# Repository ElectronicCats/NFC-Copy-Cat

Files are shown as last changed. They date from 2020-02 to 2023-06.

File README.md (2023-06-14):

# NFC Copy Cat

NFC Copy Cat, manufactured by Electronic Cats, is a small device that combines two powerful cybersecurity tools, NFCopy and MagSpoof. NFCopy works by reading or emulating an NFC card; depending on the necessities of the researcher. On the other hand, MagSpoof can wirelessly emulate/spoof any magnetic stripe card. So using NFC Copy Cat, the user will have a device capable of storing magnetic stripe data or NFC payment data to be replayed later — known in the cybersecurity world as a replay attack. 

To show the capabilities of NFC Copy Cat, the emulation example will use a Visa MSD protocol. So be aware that this type of transaction will not be accepted in some payment systems.

NFC Copy Cat combines a simple user interface that can be programmed using Arduino IDE. Adding a micro USB connection, 3.7V LiPo battery connector, antenna, two programmable buttons, LEDs and a reset button. The most important part, NFC Copy Cat is an open hardware project. So anyone could modify or redesign it on their own.

Devices like NFC Copy Cat are essential for researchers, students, teachers or anyone interested in payment systems. It will help to understand how the payment system works, the communications or the APDU protocol. 

Some of the code examples that will be available introduce different concepts. For example, how to detect a card reader, how to detect an NFC card, how to use MagSpoof using a button as a trigger to spoof, how to use NFC with a button to emulate, how to read a Visa card, how to emulate a Visa MSD card, how to generate challenges to extract card information or how to combine both tools: NFCopy and MagSpoof.

## Features:
- Microcontroller SAMD21 ARM 32-bit Cortex M0
- Memory Flash for support Circuit Python
- Battery Charger 3.7v
- Compatible con Adafruit PN532 breakout
- Compatible con NFC Module V3

### Included Complete Version:
- NFC Copy Cat
- Coil for Magspoof
- NFC Module V3 +Tag 
### Included Single Version:
- NFC Copy Cat
- Coil for Magspoof

<a href="https://electroniccats.com/store/nfc-copy-cat/">
  
</a>

## Wiki and Getting Started
[Getting Started in our Wiki](https://github.com/ElectronicCats/NFC-Copy-Cat/wiki)



## Disclaimer
NFC Copy Cat is a wireless penetration testing tool intended solely for use in authorized security audits, where such usage is permitted by applicable laws and regulations. Before utilizing this tool, it is crucial to ensure compliance with all relevant legal requirements and obtain appropriate permissions from the relevant authorities.

It is essential to note that the board does not provide any means or authorization to utilize credit cards or engage in any financial transactions that are not legally authorized. Electronic Cats holds no responsibility for any unauthorized use of the tool or any resulting damages.

## License
OpenSourceLicense

Electronic Cats invests time and resources providing this open source design, please support Electronic Cats and open-source hardware by purchasing products from Electronic Cats!

Designed by Electronic Cats.

Firmware released under an GNU AGPL v3.0 license. See the LICENSE file for more information.

Hardware released under an CERN Open Hardware Licence v1.2. See the LICENSE_HARDWARE file for more information.

Electronic Cats is a registered trademark, please do not use if you sell these PCBs.

8 July 2019

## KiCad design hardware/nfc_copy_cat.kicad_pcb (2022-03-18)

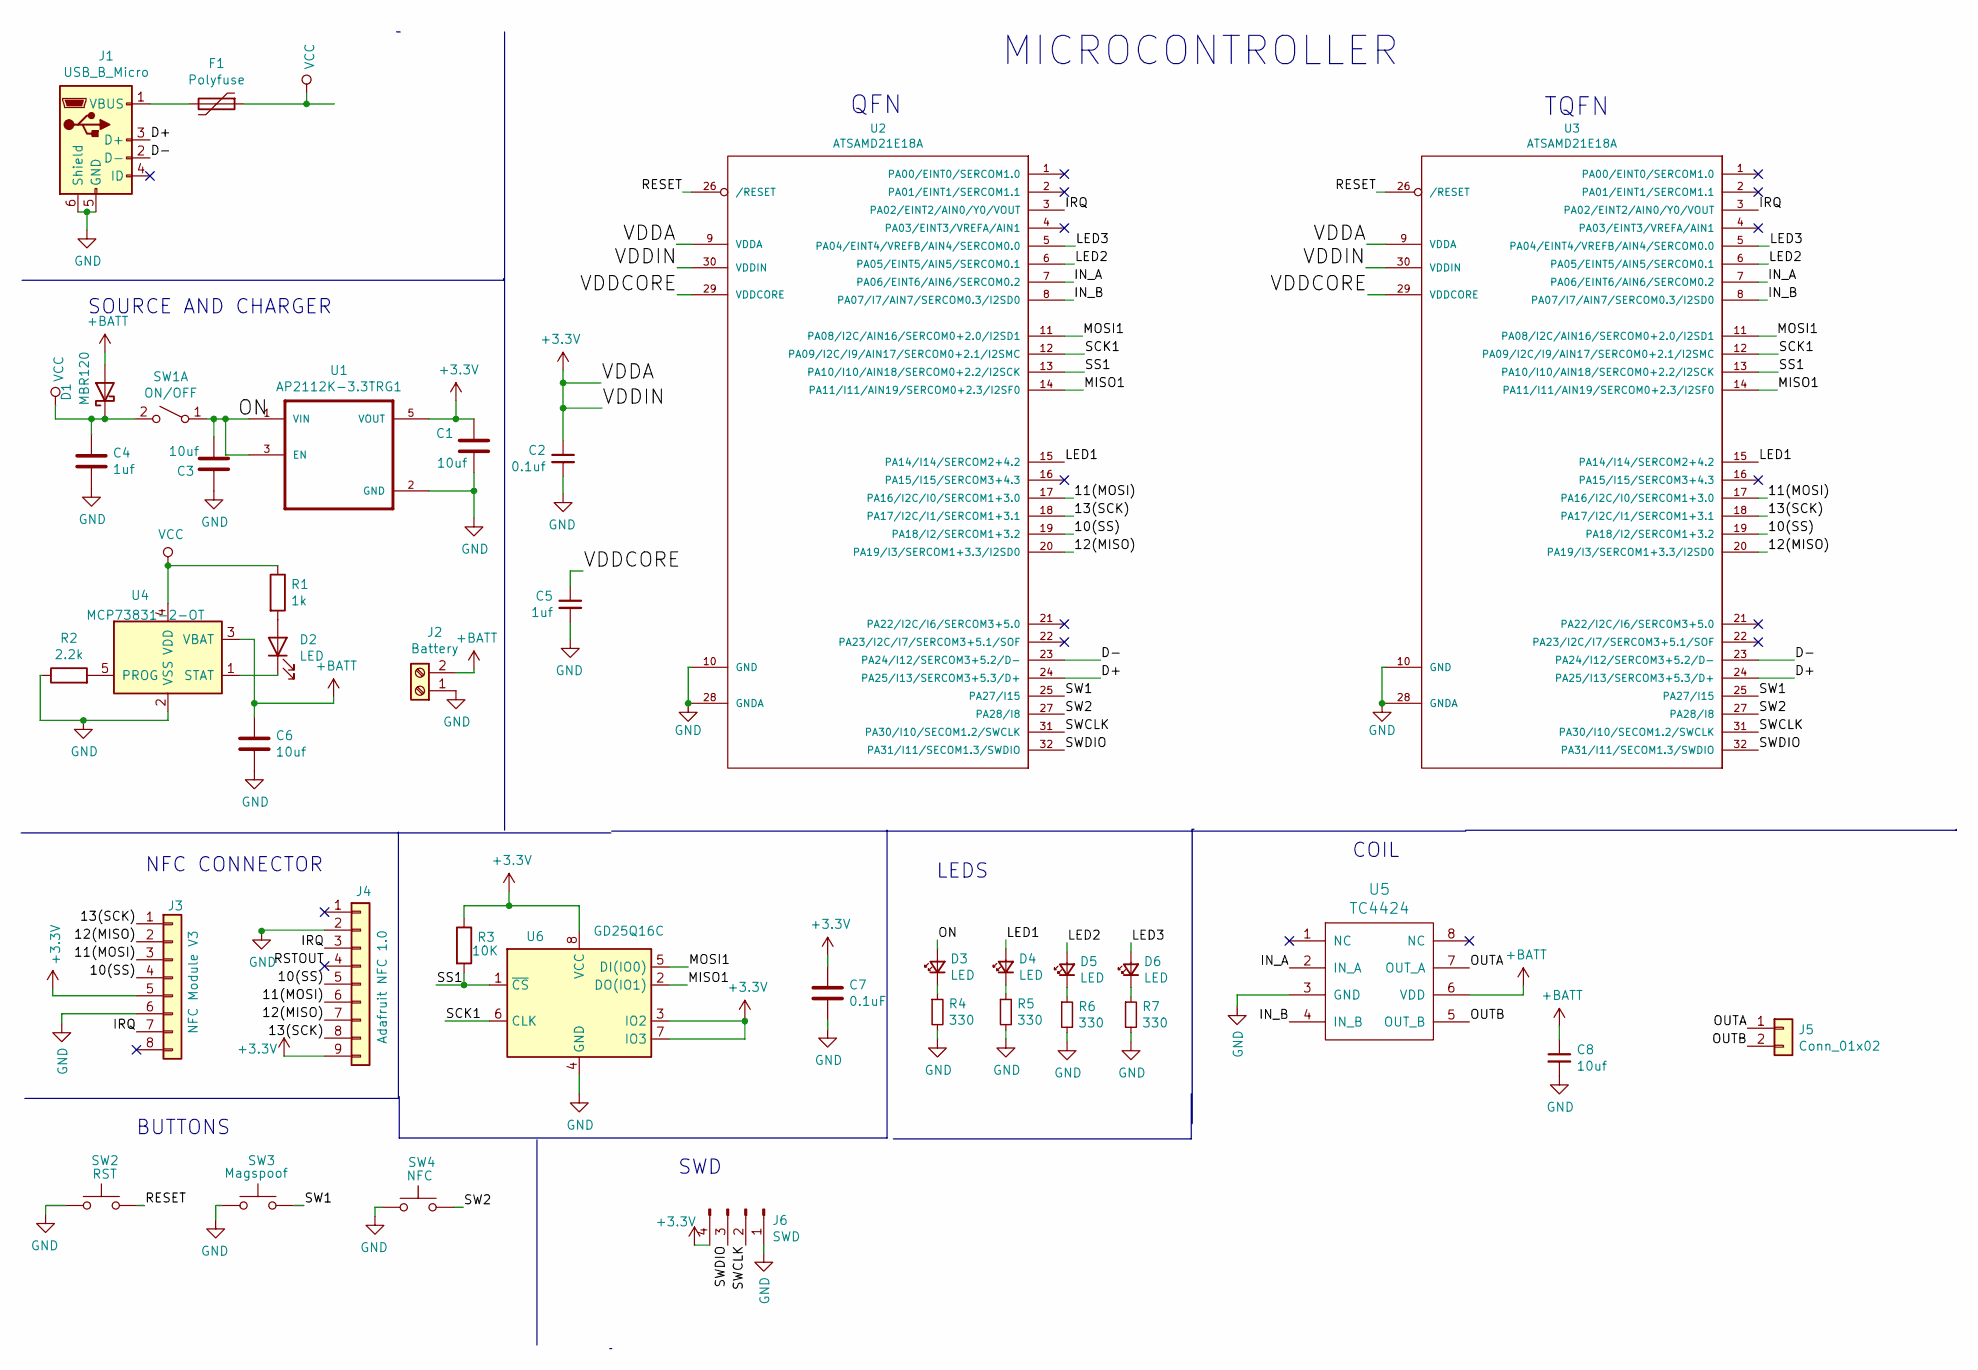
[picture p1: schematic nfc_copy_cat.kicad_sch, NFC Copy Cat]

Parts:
C1, C3, C6, C8: 10uf; C_0805_2012Metric_Pad1.15x1.40mm_HandSolder
C2: 0.1uf; C_0805_2012Metric_Pad1.15x1.40mm_HandSolder
C4, C5: 1uf; C_0805_2012Metric_Pad1.15x1.40mm_HandSolder
C7: 0.1uF; C_0805_2012Metric_Pad1.15x1.40mm_HandSolder
D1: MBR120; D_SOD-123
D2, D3, D4, D5, D6: LED; LED_0805_2012Metric_Pad1.15x1.40mm_HandSolder
F1: Polyfuse; Fuse_0805_2012Metric_Pad1.15x1.40mm_HandSolder
J1: USB_B_Micro; U254051N4BH806
J2: Battery; PinHeader_1x02_P2.54mm_Vertical
J3: NFC Module V3; PinHeader_1x08_P2.54mm_Vertical
J4: Adafruit NFC 1.0; PinHeader_1x09_P2.54mm_Vertical
J5: Conn_01x02; PinHeader_1x02_P2.54mm_Vertical
J6: SWD; PinHeader_1x04_P2.54mm_Vertical
R1: 1k; R_0805_2012Metric
R2: 2.2k; R_0805_2012Metric_Pad1.15x1.40mm_HandSolder
R3: 10K; R_0805_2012Metric_Pad1.15x1.40mm_HandSolder
R4: 330; R_0805_2012Metric
R5, R6, R7: 330; R_0805_2012Metric_Pad1.15x1.40mm_HandSolder
SW1: ON/OFF; Micro_interruptor_SPDT
SW2: RST; SW_SPST_TL3342
SW3: Magspoof; SW_SPST_TL3342
SW4: NFC; SW_SPST_TL3342
U1: AP2112K-3.3TRG1; SOT-23-5_HandSoldering
U2: ATSAMD21E18A; QFN-32-1EP_5x5mm_P0.5mm_EP3.6x3.6mm
U3: ATSAMD21E18A; TQFP-32_7x7mm_P0.8mm
U4: MCP73831-2-OT; SOT-23-5
U5: TC4424; SOIC-8_3.9x4.9mm_P1.27mm
U6: GD25Q16C; SOIC-8_5.23x5.23mm_P1.27mm

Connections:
+3V3: C1.1, C2.1, C7.1, J3.5, J4.9, J6.4, R3.1, U1.5 (VOUT), U2.9 (VDDA), U2.30 (VDDIN), U3.9 (VDDA), U3.30 (VDDIN), U6.3 (IO2), U6.7 (IO3), U6.8 (VCC)
+BATT: C6.1, C8.1, D1.2 (A), J2.2, U4.3 (VBAT), U5.6 (VDD)
/10(SS): J3.4, J4.5, U2.19 (PA18/I2/SERCOM1+3.2), U3.19 (PA18/I2/SERCOM1+3.2)
/11(MOSI): J3.3, J4.6, U2.17 (PA16/I2C/I0/SERCOM1+3.0), U3.17 (PA16/I2C/I0/SERCOM1+3.0)
/12(MISO): J3.2, J4.7, U2.20 (PA19/I3/SERCOM1+3.3/I2SD0), U3.20 (PA19/I3/SERCOM1+3.3/I2SD0)
/13(SCK): J3.1, J4.8, U2.18 (PA17/I2C/I1/SERCOM1+3.1), U3.18 (PA17/I2C/I1/SERCOM1+3.1)
/D+: J1.3 (D+), U2.24 (PA25/I13/SERCOM3+5.3/D+), U3.24 (PA25/I13/SERCOM3+5.3/D+)
/D-: J1.2 (D-), U2.23 (PA24/I12/SERCOM3+5.2/D-), U3.23 (PA24/I12/SERCOM3+5.2/D-)
/IN_A: U2.7 (PA06/EINT6/AIN6/SERCOM0.2), U3.7 (PA06/EINT6/AIN6/SERCOM0.2), U5.2 (IN_A)
/IN_B: U2.8 (PA07/I7/AIN7/SERCOM0.3/I2SD0), U3.8 (PA07/I7/AIN7/SERCOM0.3/I2SD0), U5.4 (IN_B)
/IRQ: J3.7, J4.3, U2.3 (PA02/EINT2/AIN0/Y0/VOUT), U3.3 (PA02/EINT2/AIN0/Y0/VOUT)
/LED1: D4.2 (A), U2.15 (PA14/I14/SERCOM2+4.2), U3.15 (PA14/I14/SERCOM2+4.2)
/LED2: D5.2 (A), U2.6 (PA05/EINT5/AIN5/SERCOM0.1), U3.6 (PA05/EINT5/AIN5/SERCOM0.1)
/LED3: D6.2 (A), U2.5 (PA04/EINT4/VREFB/AIN4/SERCOM0.0), U3.5 (PA04/EINT4/VREFB/AIN4/SERCOM0.0)
/MISO1: U2.14 (PA11/I11/AIN19/SERCOM0+2.3/I2SF0), U3.14 (PA11/I11/AIN19/SERCOM0+2.3/I2SF0), U6.2 (DO(IO1))
/MOSI1: U2.11 (PA08/I2C/AIN16/SERCOM0+2.0/I2SD1), U3.11 (PA08/I2C/AIN16/SERCOM0+2.0/I2SD1), U6.5 (DI(IO0))
/OUTA: J5.1, U5.7 (OUT_A)
/OUTB: J5.2, U5.5 (OUT_B)
/RESET: SW2.2, U2.26 (/RESET), U3.26 (/RESET)
/RSTOUT: J4.4
/SCK1: U2.12 (PA09/I2C/I9/AIN17/SERCOM0+2.1/I2SMC), U3.12 (PA09/I2C/I9/AIN17/SERCOM0+2.1/I2SMC), U6.6 (CLK)
/SS1: R3.2, U2.13 (PA10/I10/AIN18/SERCOM0+2.2/I2SCK), U3.13 (PA10/I10/AIN18/SERCOM0+2.2/I2SCK), U6.1 (~CS)
/SW1: SW3.2, U2.25 (PA27/I15), U3.25 (PA27/I15)
/SW2: SW4.2, U2.27 (PA28/I8), U3.27 (PA28/I8)
/SWCLK: J6.2, U2.31 (PA30/I10/SECOM1.2/SWCLK), U3.31 (PA30/I10/SECOM1.2/SWCLK)
/SWDIO: J6.3, U2.32 (PA31/I11/SECOM1.3/SWDIO), U3.32 (PA31/I11/SECOM1.3/SWDIO)
/VDDCORE: C5.1, U2.29 (VDDCORE), U3.29 (VDDCORE)
GND: C1.2, C2.2, C3.2, C4.2, C5.2, C6.2, C7.2, C8.2, J1.5 (GND), J1.6 (Shield), J2.1, J3.6, J4.2, J6.1, R2.1, R4.2, R5.2, R6.2, R7.2, SW2.1, SW3.1, SW4.1, U1.2 (GND), U2.10 (GND), U2.28 (GNDA), U3.10 (GND), U3.28 (GNDA), U4.2 (VSS), U5.3 (GND), U6.4 (GND)
unnamed: D2.1 (K), U4.1 (STAT)
unnamed: D2.2 (A), R1.2
unnamed: D3.1 (K), R4.1
unnamed: D4.1 (K), R5.1
unnamed: D5.1 (K), R6.1
unnamed: D6.1 (K), R7.1
unnamed: F1.2, J1.1 (VBUS)
unnamed: R2.2, U4.5 (PROG)

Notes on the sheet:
QFN
NFC CONNECTOR
LEDS
SWD
TQFN
SOURCE AND CHARGER
COIL
BUTTONS
MICROCONTROLLER

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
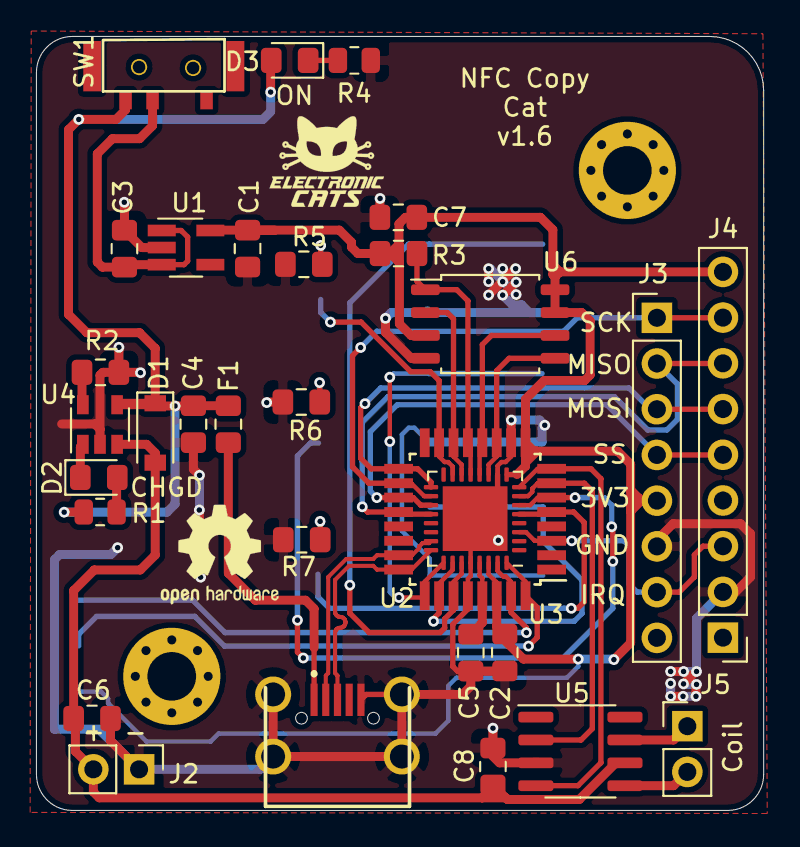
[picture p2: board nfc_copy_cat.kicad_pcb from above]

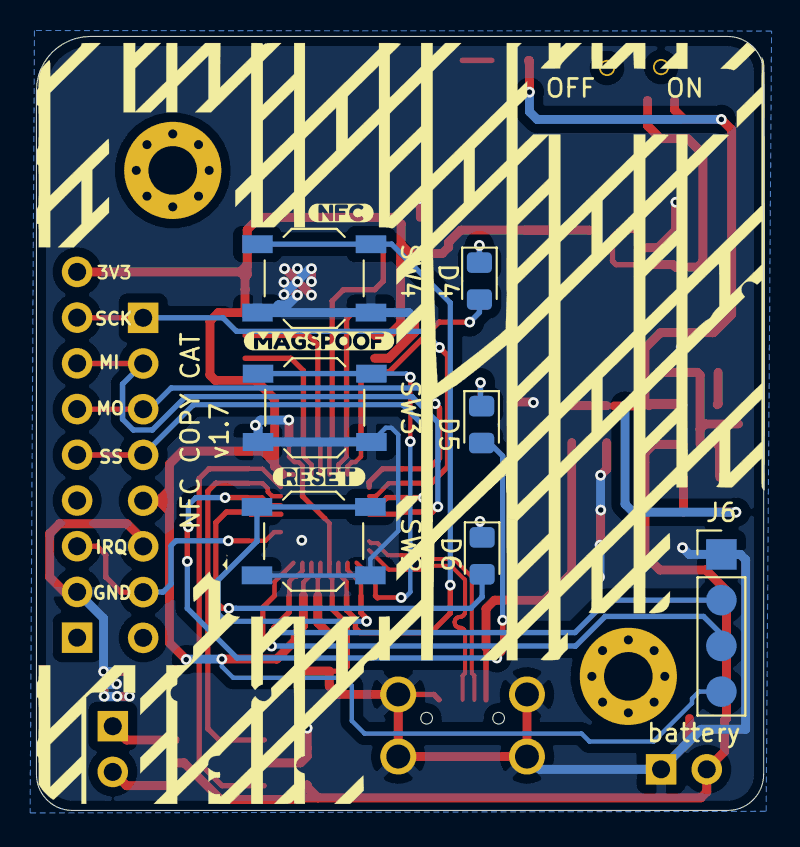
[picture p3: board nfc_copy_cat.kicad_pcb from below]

Board: 2 copper layers, 40.4 x 43.0 mm, 43 parts (10 on the bottom side), 37 nets.

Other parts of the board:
 : MountingHole_2.7mm_M2.5_Pad_Via
 #2: MountingHole_2.7mm_M2.5_Pad_Via
kibuzzard-6234C9E0: G***; kibuzzard-6234C9E0
kibuzzard-6234C9F1: G***; kibuzzard-6234C9F1
kibuzzard-6234C9FD: G***; kibuzzard-6234C9FD

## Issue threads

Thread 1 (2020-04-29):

bootloader

K1two2, 2020-04-29:
NFC Copy Cat is an interesting project. I made several PCBs. How can I burn the bootloader?

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

sabas1080, 2020-04-29:
@K1two2 Hi, wow interesting, for burn bootloader you can use a SWD programmer as Jlink or Baclkmagic in J3

Binary available in https://github.com/ElectronicCats/Arduino_Boards_Index/tree/gh-pages/electroniccats/samd/bootloaders/nfc_copy_cat

K1two2, 2020-04-29:
Thank you, sir ~
I have been trying to search for information about the uf2 bootloader, and it turns out that there are ready-made BIN firmware downloads in the Arduino Boards Index.
hahaha~

K1two2, 2020-04-29:
> @K1two2 Hi, wow interesting, for burn bootloader you can use a SWD programmer as Jlink or Baclkmagic in J3
>
> Binary available in https://github.com/ElectronicCats/Arduino_Boards_Index/tree/gh-pages/electroniccats/samd/bootloaders/nfc_copy_cat

Thank you, sir ~
I have been trying to search for information about the uf2 bootloader, and it turns out that there are ready-made BIN firmware downloads in the Arduino Boards Index.
hahaha~

sabas1080, 2020-04-30:
Oh when you compile UF2 generate various binaries https://github.com/ElectronicCats/uf2-samd21/tree/master/boards/nfc_copy_cat

joelsernamoreno, 2021-06-06:
Hi!

The bootloader (binary) link does not exist. Where can I find it?

Thanks!

sabas1080, 2021-06-07:
@joelsernamoreno binary file in our arduiino core https://github.com/ElectronicCats/ArduinoCore-samd/tree/master/bootloaders/nfc_copy_cat

Closed 2020-04-29.

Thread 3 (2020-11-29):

Hardware setup imformation

Pdubs19, 2020-11-29:
Hey can you send some info on how to hook up and program the board with arduino mega 2560. Also any pictures and basic hardware/hookup support would be appreciated.

sabas1080, 2020-11-29:
Can you explain a little more what you want to do? NFC copy cat uses a SAMD21

Pdubs19, 2020-11-29:
Just want to be able to run the nfc read and be able to spoof magstripes.
So really the read replay spoof code. I'm new to programming circuit
boards. I have an arduino uno and mega. I'm just looking for a little more
info on how the board works. Do I just need to program the pn532 board and
connect it to the nfc copycat board. I got the nfc copycat into bootloader
mode but am not really sure how to program the nfc and magspoof buttons

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

Pdubs19, 2020-11-29:
The samd21 mi

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

Pdubs19, 2020-11-29:
I have the samd21 micro controller nfc copy cat 1.4v board with the electro
house nfc v3 board.

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

sabas1080, 2020-11-30:
@Pdubs19 Have you already consulted our wiki?

https://github.com/ElectronicCats/NFC-Copy-Cat/wiki

Pdubs19, 2020-11-30:
Yes. All I'm really wondering is if I need to program either the nfc
copycat samd21 board or the pn532 nxp board separately or if I only have to
program one of them and then connect the boards together. Ik this is a
newbie question but I really want to make this device work. Also does the
samd21 board coil connect to the nxp pn532 coil somehow for the read replay
spoof programming

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

Pdubs19, 2020-11-30:
Don't want to waste anyone's time but anymore pictures and basic info on
how to start and which boards have to be programmed and what order etc.
would be greatly apprecisted.

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

Pdubs19, 2020-12-05:
For Magpoof coil

#define L1 (14) //LED1

#define L2 (5) //LED2

#define L3 (4) //LED3

For Buttons

#define MPIN (28) //MagsSpoof Button

#define NPIN (27) //NFC Button

Does this mean I need to connect the LED 1 to 14 on the arduino?  If so what it's the connection for LED 1 on the nfc samd21 nfc board?

FelipeIslas, 2020-12-10:
Hi @Pdubs19
We are using our NFC Copy-Cat, which as you say has a SAMD21, this board has 3 onboard programmable LEDs and they are on pin 14, 4 and 5, so in the example these numbers are used for those LEDs.
Our Wiki was Updated, now it is a little clearer!!! I recommend you see it to clarify some of your doubts

Pdubs19, 2020-12-11:
Yo thanks for the new wiki feels like Christmas has come early. I'm totally new to programming but couldn't resist buying the nfc copy cat once I read about it.

Closed 2020-12-11.

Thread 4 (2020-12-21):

Is there a program or tutorial to decode the nfc tag data or msd data?

Pdubs19, 2020-12-21:
Is there any tutorials of sites with more info on decrypting nfc data and converting it to magstripe data. My main question is why is Magstripe data so important? How did Samy Kamkar figure out what parts of track 2 discretionary data needed to be changed in order to downgrade the service code from 201 to 101. Was his downgrade method simply using his algorithim to use a previous cards CVC3 or CVV2 on the magstripe and apply it to the new card?

Pdubs19, 2020-12-29:
Any suggestions for the best programs to use for going through the nfc data while using arduino? Rn I've been using arduino's serial monitor or putty connected to the serial port.

Pdubs19, 2020-12-29:
Any ideas on the best software to use for decrypting the nfc data on windows 10

salmg, 2020-12-29:
Hello @Pdubs19

Answering your questions:
1. "is why is Magstripe data so important?" - Because it what the payment systems implements to charge amount to an account. The mag-stripe contains all the necessary data to do that, such as, PAN, expiration date, service code, discretionary data...

2. "How did Samy Kamkar figure out what parts of track 2 discretionary data needed to be changed in order to downgrade the service code from 201 to 101." - It is a legacy compatibility in the payment systems to be able to do different payments without denying most of the transactions & because Samy is so smart.

3. "Was his downgrade method simply using his algorithim to use a previous cards CVC3 or CVV2 on the magstripe and apply it to the new card?" - This replay attack only works in the Visa cards CVV mag-stripe data, as I mentioned before it works because compatibility.

4. "Does this device not save the info in order to spoof nfc and magspoof once the power is disconnected." - No, the device will not save the data that read afterwards. It will only save the track you assigned in the code.

To decode EMV, you can read the books in NFC Forum: https://www.emvco.com/emv-technologies/contact/

An online service that helps to decode EMV data automatically: https://emvlab.org/tlvutils/

Closed 2020-12-31.

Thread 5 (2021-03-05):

Help with PDOL challenge

merdeux50, 2021-03-05:
Hello,

I’ve recently gotten a nfc copy cat and am struggling to understand how to run the read_replay_spoof .ino

could someone please clarify what “ Make a right format challenge using the card PDOL to extract more data(track 2)” means? And how I should go editing the ino?

ive successfully got my cards pdol with the acr122 and cardpeek what next?

salmg, 2021-03-07:
If you got the pdol from the acr122 means that you got the track 2 as well.

Just add the track 2 to the token variable. There is an example in the code such as

 char token[19] = {0x44,0x12,0x34,0x15,0x01,0x12,0x03,0x12,0xd2,0x41,0x12,0x01,0x10,0x12,0x09,0x99,0x99,0x99,0x1f};

and then emulate it.

merdeux50, 2021-03-07:
Thank you for your reply, yes I can use it. But what’s the point in having bought the nfc copy cat with the ability to extract it through the pn 352 if I have to use another device?

How can I successfully use the copy cat?

salmg, 2021-03-07:
The PDOL function was designed to challenge the card, to be able to extract track 2, NFC Copy Cat has to send the correct challenge at least in format to the card. That is what PDOL does. Basically it generates the "GET PROCESSING OPTIONS" command in format, so the card can answer with the track 2

Really you do not have to edit the code to work; this code is ready to use, if you press a button and it will spoof data, if you press the second one, it will try yo read the card automatically.

If you want to learn about what is pdol: https://www.emvco.com/wp-content/uploads/2017/05/EMV_v4.3_Book_3_Application_Specification_20120607062110791.pdf

If you want to learn more about the tool: https://salmg.net/2020/04/13/nfc-copy-cat-magstripe-nfc/ or

merdeux50, 2021-03-08:
Thank you!

I will read all I can to understand the communication with the card.
It seems after trying the CheckPDOL I get (This card is not active btw...)

9.934 -> Command: 0x00 0xA4 0x04 0x00 0x0E 0x32 0x50 0x41 0x59 0x2E 0x53 0x59 0x53 0x2E 0x44 0x44 0x46 0x30 0x31 0x00
09:17:50.006 -> Card answer: 0x6F 0x23 0x84 0x0E 0x32 0x50 0x41 0x59 0x2E 0x53 0x59 0x53 0x2E 0x44 0x44 0x46 0x30 0x31 0xA5 0x11 0xBF 0x0C 0x0E 0x61 0x0C 0x4F 0x07 0xA0 0x00 0x00 0x00 0x03
09:17:50.006 -> -----
09:17:50.331 -> Command: 0x00 0xA4 0x04 0x00 0x07 0xA0 0x00 0x00 0x00 0x03 0x10 0x10 0x00
09:17:50.443 -> Card answer: 0x6F 0x5E 0x84 0x07 0xA0 0x00 0x00 0x00 0x03 0x10 0x10 0xA5 0x53 0x50 0x0B 0x56 0x69 0x73 0x61 0x20 0x43 0x72 0x65 0x64 0x69 0x74 0x87 0x01 0x01 0x9F 0x38 0x18
09:17:50.443 -> -----
09:17:50.443 -> -->PDOL found: 0x18 0x00 0x00 0x00 0x00 0x00 0x00 0x00 0x00 0x00 0x00 0x00 0x00 0x00 0x00 0x00 0x00 0x00 0x00 0x00 0x00 0x00 0x00 0x00 0x00
09:17:50.443 -> -----
09:17:50.757 -> Command: 0x80 0xA8 0x00 0x00 0x23 0x83 0x21 0x00
09:17:50.793 -> Card answer: 0x6F 0x00
09:17:50.793 -> -----
09:17:51.084 -> Command: 0x00 0xB2 0x01 0x0C 0x00
09:17:51.117 -> Card answer: 0x6A 0x83

Comparing the card answer with cardpeek, 3 lines of data are missing in the response to the visa command. That might be why I can't seem to get it to work?

merdeux50, 2021-03-12:
Any insight regarding the pdol check?

merdeux50, 2021-03-18:
After reading most of the documents I found. I’m realizing that the script is fine.
For some reason the cards responses to the APDU and visa is too short for it to get the normal pdol.

There is a communication error somewhere.

The PN532 board is unreliable, it recognizes the board 1 out of 30 times.

Honestly guy, this is supposed to be for students and people that want to learn?
I’ve had an extremely uninterested and lazy response from all of you guys here. Giving me lazy responses.

Just take the money and run type of mentality.

I’m disappointed

wero1414, 2021-03-23:
Hi @merdeux50 im really sorry about the timming on answering your issue, i must say our technical team is quite small and we're now focused on a new product, The Hunter Cat NFC we have noticed on the past the problem with the PN532 board sometimes it works in a bad way, talking in other topic, the maspoof should work as thats something that we always test on our product line

merdeux50, 2021-03-24:
I noticed a crucial thing missing from your wiki which solved most of my issues.

I was using the Adafruit PN532 library, I changed it to salm pn532 library and it works better now.

merdeux50, 2021-03-25:
That’s unbelievable!

You should have told me that you guys were coming out with a new product - nfc hunter cat. Instead I bought the nfc copy cat that doesn’t work because of the crappy PN532 board. Come on guys, why?
You knew I had monetary issues since is asked for a coupon, which was denied.

Closed 2021-03-24.

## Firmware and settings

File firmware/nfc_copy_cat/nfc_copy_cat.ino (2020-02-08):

/************************************************************
  NFC Copy Cat
  by Salvador Mendoza (salmg.net)
  for Electronic Cats
   
  This example demonstrates how to use NFC Copy Cat by Electronic Cats
  https://github.com/ElectronicCats/magspoof
  
  Development environment specifics:
  IDE: Arduino 1.8.9
  Hardware Platform:
  NFC Copy Cat
  - SAMD21E
  
  This code is beerware; if you see me (or any other Electronic Cats
  member) at the local, and you've found our code helpful,
  please buy us a round!
  Distributed as-is; no warranty is given.
*/
#include <Wire.h>
#include <SPI.h>
#include <Adafruit_PN532.h>

#define PN532_SCK  (17)
#define PN532_MOSI (16)
#define PN532_SS   (18)
#define PN532_MISO (19)

#define PN532_IRQ   (2)
#define PN532_RESET (3)

Adafruit_PN532 nfc(PN532_SCK, PN532_MISO, PN532_MOSI, PN532_SS);

#if defined(ARDUINO_ARCH_SAMD)
   #define Serial SerialUSB
#endif
int lectura;
void setup() {
  pinMode(8,OUTPUT);
  pinMode(9,OUTPUT);
  pinMode(6,INPUT_PULLUP);
pinMode(7,INPUT_PULLUP);
  #ifndef ESP8266
//    while (!Serial); // for Leonardo/Micro/Zero
  #endif
  Serial.begin(115200);
  Serial.println("Hello!");
lectura=0;
  nfc.begin();



  uint32_t versiondata = nfc.getFirmwareVersion();
  if (! versiondata) {
    Serial.print("Didn't find PN53x board");
    while (1); // halt
  }
  // Got ok data, print it out!
    Serial.println("Hello!");
  Serial.print("Found chip PN5"); Serial.println((versiondata>>24) & 0xFF, HEX); 
  Serial.print("Firmware ver. "); Serial.print((versiondata>>16) & 0xFF, DEC); 
  Serial.print('.'); Serial.println((versiondata>>8) & 0xFF, DEC);
  
  // configure board to read RFID tags
  nfc.SAMConfig();
  
  Serial.println("Waiting for an ISO14443A Card ...");
}

void loop() {        
      digitalWrite(8,LOW);
      digitalWrite(9,LOW);
  // put your main code here, to run repeatedly:
if((digitalRead(6)!=1)){

  Serial.println("\n             ");
  Serial.println("Hello");
    Serial.println("NFC Sensor ON");
  lectura=0;
  delay(100);
    Serial.println("Put your NFC Card on the sensor");  
digitalWrite(8,LOW);
digitalWrite(9,LOW);

   uint8_t success;
  uint8_t uid[] = { 0, 0, 0, 0, 0, 0, 0 };  // Buffer to store the returned UID
  uint8_t uidLength;                        // Length of the UID (4 or 7 bytes depending on ISO14443A card type)
    
  // Wait for an ISO14443A type cards (Mifare, etc.).  When one is found
  // 'uid' will be populated with the UID, and uidLength will indicate
  // if the uid is 4 bytes (Mifare Classic) or 7 bytes (Mifare Ultralight)
  success = nfc.readPassiveTargetID(PN532_MIFARE_ISO14443A, uid, &uidLength);
  
  if (success) {
    // Display some basic information about the card
    Serial.println("Found an ISO14443A card");
    Serial.print("  UID Length: ");Serial.print(uidLength, DEC);Serial.println(" bytes");
    Serial.print("  UID Value: ");


    nfc.PrintHex(uid, uidLength);
    Serial.println("");
    
    if (uidLength == 4)
    {
      // We probably have a Mifare Classic card ... 
      Serial.println("Seems to be a Mifare Classic card (4 byte UID)");
   
      // Now we need to try to authenticate it for read/write access
      // Try with the factory default KeyA: 0xFF 0xFF 0xFF 0xFF 0xFF 0xFF
      Serial.println("Trying to authenticate block 4 with default KEYA value");
      lectura=1;
      uint8_t keya[6] = { 0xFF, 0xFF, 0xFF, 0xFF, 0xFF, 0xFF };
    
    // Start with block 4 (the first block of sector 1) since sector 0
    // contains the manufacturer data and it's probably better just
    // to leave it alone unless you know what you're doing
      success = nfc.mifareclassic_AuthenticateBlock(uid, uidLength, 4, 0, keya);
    
      if (success)
      {
        Serial.println("Sector 1 (Blocks 4..7) has been authenticated");
        uint8_t data[16];
    
        // If you want to write something to block 4 to test with, uncomment
    // the following line and this text should be read back in a minute
        //memcpy(data, (const uint8_t[]){ 'a', 'd', 'a', 'f', 'r', 'u', 'i', 't', '.', 'c', 'o', 'm', 0, 0, 0, 0 }, sizeof data);
        // success = nfc.mifareclassic_WriteDataBlock (4, data);

        // Try to read the contents of block 4
        success = nfc.mifareclassic_ReadDataBlock(4, data);
    
        if (success)
        {
          // Data seems to have been read ... spit it out
          Serial.println("Reading Block 4:");
          nfc.PrintHexChar(data, 16);
          Serial.println("");
      
          // Wait a bit before reading the card again

        }
        else
        {
          Serial.println("Ooops ... unable to read the requested block.  Try another key?");
        }
      }
      else
      {
        Serial.println("Ooops ... authentication failed: Try another key?");
      }
    }
    
    if (uidLength == 7)
    {
      // We probably have a Mifare Ultralight card ...
      Serial.println("Seems to be a Mifare Ultralight tag (7 byte UID)");
    
      // Try to read the first general-purpose user page (#4)
      Serial.println("Reading page 4");
      uint8_t data[32];
      success = nfc.mifareultralight_ReadPage (4, data);
      if (success)
      {
        // Data seems to have been read ... spit it out
        nfc.PrintHexChar(data, 4);
        Serial.println("");
    
        // Wait a bit before reading the card again

      }
      else
      {
        Serial.println("Ooops ... unable to read the requested page!?");
      }
    }
  }
}
if((digitalRead(7)!=1)&&(lectura!=0)){
Serial.print("send data"); 
      digitalWrite(8,LOW);
      digitalWrite(9,HIGH);
      delay(2000);
      lectura=0;
}
}

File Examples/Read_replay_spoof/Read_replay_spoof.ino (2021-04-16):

/**
 * Example to extract track 2 from a NFC transaction and emulate a Visa MSD transaction or 
 * spoof magnetic data with MagSpoof 
 * 
 * Authors: 
 *        Salvador Mendoza - @Netxing - salmg.net
 *        For Electronic Cats - electroniccats.com
 * 
 *  April 2020
 * 
 * This code is beerware; if you see me (or any other collaborator 
 * member) at the local, and you've found our code helpful, 
 * please buy us a round!
 * Distributed as-is; no warranty is given.
 */

/* Important:
 "token" variable is used for NFC.
 "tokenString" variable is used for MagSpoof after a NFC track 2 extraction.

  - If "token" variable is "empty", the NFC button will activate the "reading" feature 
 to try to obtain the track 2 from a NFC card and display its content over USB. Also, if 
 the track 2 is detected in the NFC reading, it will be saved in both "token" and "tokenString" 
 variables to be used for emulating a NFC transaction or as magstripe data for MagSpoof without 
 reprogramming. This new behavior will be notorious by LEDs.
 
 Basically, "token" and "tokenString" are used to store a sniffed track 2 from a NFC reading. 

 Futhermore, it is possible to initialize this variables with valid data. 
 If so, the NFC button will activate the "emulation" mode using the data in the "token" 
 variable instead of reading the card.

 Example to initialized this variable with card data to emulate NFC transaction instead of reading if need it:
 
 char token[19] = {0x44,0x12,0x34,0x15,0x01,0x12,0x03,0x12,0xd2,0x41,0x12,0x01,0x10,0x12,0x09,0x99,0x99,0x99,0x1f};

 The C-APDU command length can be up to 261 bytes (CLA-INS-P1-P2-P3-255 data bytes-Le) and 
 the R-APDU returned to the host controller can have a length of 258 bytes (256 data bytes-SW1-SW2).
*/

#include <Wire.h>
#include <SPI.h>
#include <Adafruit_PN532.h>
#include "SdFat.h"
#include "Adafruit_SPIFlash.h"

#define PN532_SCK  (17)
#define PN532_MOSI (16)
#define PN532_SS   (18)
#define PN532_MISO (19)

#define L1         (14) //LED1 indicates activity
#define L2         (5)  //LED2 indicates that track 2 is saved in "token" variable for NFC emulation purposes
#define L3         (4)  //LED3 indicates that track 2 is saved in "tokenString variable for MagSpoof purposes

#define PIN_A      (6)  //MagSpoof pin output
#define PIN_B      (7)  //MagSpoof pin output

#define MPIN       (28) //MagsSpoof Button
#define NPIN       (27) //NFC Button

#define NFCT       (3)  //How many times to emulate the card

#define CLOCK_US   (500)

#define BETWEEN_ZERO (53) // 53 zeros between track1 & 2

#define TRACKS (2)
#define DEBUGCAT

Adafruit_PN532 nfc(PN532_SCK, PN532_MISO, PN532_MOSI, PN532_SS);

Adafruit_FlashTransport_SPI flashTransport(EXTERNAL_FLASH_USE_CS, EXTERNAL_FLASH_USE_SPI);

Adafruit_SPIFlash flash(&flashTransport);

// consts get stored in flash as we don't adjust them
const char* tracks[] = {
  "%B123456781234567^LASTNAME/FIRST^YYMMSSSDDDDDDDDDDDDDDDDDDDDDDDDD?\0", // Track 1
  ";123456781234567=112220100000000000000?\0" // Track 2
};

char token[19];
String tokenString = "";

uint8_t ppdol [255] = {0x80, 0xA8, 0x00, 0x00, 0x02, 0x83, 0x00};

char revTrack[41];
const int sublen[] = {
  32, 48, 48 
};
const int bitlen[] = {
  7, 5, 5 
};
unsigned int curTrack = 0;
int dir;

void setup(){
  pinMode(PIN_A, OUTPUT);
  pinMode(PIN_B, OUTPUT);
  pinMode(L1, OUTPUT);
  pinMode(L2, OUTPUT);
  pinMode(L3, OUTPUT);
  pinMode(MPIN, INPUT_PULLUP);
  pinMode(NPIN, INPUT_PULLUP);

  Serial.begin(9600);
  while(!Serial);
  
  // Initialize flash library and check its chip ID.
  if (!flash.begin()) {
    Serial.println("Error, failed to initialize flash chip!");
    while (1) {
      blink(LED_BUILTIN, 600, 3);;
    }
  }
  Serial.print("Flash chip JEDEC ID: 0x"); Serial.println(flash.getJEDECID(), HEX);

  nfc.begin();

  uint32_t versiondata = nfc.getFirmwareVersion();
  if (! versiondata) {
    Serial.print("Didn't find PN53x board");
    while (1); // halt
  }

  // blink to show we started up
  blink(L1, 200, 2);
  blink(L2, 200, 2);
  blink(L3, 200, 2);
  
  // Got ok data, print it out!
  Serial.print("Found chip PN5"); Serial.println((versiondata>>24) & 0xFF, HEX); 
  Serial.print("Firmware ver. "); Serial.print((versiondata>>16) & 0xFF, DEC); 
  Serial.print('.'); Serial.println((versiondata>>8) & 0xFF, DEC);
  
  nfc.setPassiveActivationRetries(0xFF);
  
  // configure board to read RFID tags
  nfc.SAMConfig();
  
  // store reverse track 2 to play later
  storeRevTrack(2);
}

void blink(int pin, int msdelay, int times){
  for (int i = 0; i < times; i++){
    digitalWrite(pin, HIGH);
    delay(msdelay);
    digitalWrite(pin, LOW);
    delay(msdelay);
  }
}

// send a single bit out
void playBit(int sendBit){
  dir ^= 1;
  digitalWrite(PIN_A, dir);
  digitalWrite(PIN_B, !dir);
  delayMicroseconds(CLOCK_US);

  if (sendBit){
    dir ^= 1;
    digitalWrite(PIN_A, dir);
    digitalWrite(PIN_B, !dir);
  }
  delayMicroseconds(CLOCK_US);

}

// when reversing
void reverseTrack(int track){
  int i = 0;
  track--; // index 0
  dir = 0;

  while (revTrack[i++] != '\0');
  i--;
  while (i--)
    for (int j = bitlen[track]-1; j >= 0; j--)
      playBit((revTrack[i] >> j) & 1);
}

// plays out a full track, calculating CRCs and LRC
void playTrack(int track){
  int tmp, crc, lrc = 0;
  dir = 0;
  track--; // index 0
  // enable H-bridge and LED
  //digitalWrite(ENABLE_PIN, HIGH);

  // First put out a bunch of leading zeros.
  for (int i = 0; i < 25; i++)
    playBit(0);

  //(!token[0]) ? tracks[track][i] != '\0' : i <= 19
  //for (int i = 0; tracks[track][i] != '\0'; i++)
  for (int i = 0; (tokenString.length()) ? i < tokenString.length() : tracks[track][i] != '\0'; i++)
  {
    crc = 1;
    //tmp = tracks[track][i] - sublen[track];
    tmp = (tokenString.length()) ? tokenString[i] : tracks[track][i];
    tmp -= sublen[track];
    
    for (int j = 0; j < bitlen[track]-1; j++)
    {
      crc ^= tmp & 1;
      lrc ^= (tmp & 1) << j;
      playBit(tmp & 1);
      tmp >>= 1;
    }
    playBit(crc);
  }

  // finish calculating and send last "byte" (LRC)
  tmp = lrc;
  crc = 1;
  for (int j = 0; j < bitlen[track]-1; j++)
  {
    crc ^= tmp & 1;
    playBit(tmp & 1);
    tmp >>= 1;
  }
  playBit(crc);

  // if track 1, play 2nd track in reverse (like swiping back?)
  if (track == 0)
  {
    // if track 1, also play track 2 in reverse
    // zeros in between
    for (int i = 0; i < BETWEEN_ZERO; i++)
      playBit(0);

    // send second track in reverse
    reverseTrack(2);
  }

  // finish with 0's
  for (int i = 0; i < 5 * 5; i++)
    playBit(0);

  digitalWrite(PIN_A, LOW);
  digitalWrite(PIN_B, LOW);
  //digitalWrite(ENABLE_PIN, LOW);

}
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

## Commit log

2019-07-08 primer commit de hardware
    [placa inventors house 1.kicad_pcb, placa inventors house 1.sch]
2019-07-08 Typo fix
    [nfc_copy_cat.kicad_pcb, nfc_copy_cat.sch]
2019-07-08 typo xD
    [nfc_copy_cat.kicad_pcb, nfc_copy_cat.sch]
2019-07-22 añadimiento de led
    [nfc_copy_cat.kicad_pcb, nfc_copy_cat.sch]
2019-08-02 desplazamiento de botones haca atras
    [nfc_copy_cat.kicad_pcb]
2019-10-30 update schematic
    new connector swd, fix cap vddcore, add leds
    [nfc_copy_cat.sch]
2019-10-31 add connector adafruit NFC
    [nfc_copy_cat.sch]
2019-11-15 Update traces, USB port and version 1.3v
    [nfc_copy_cat.kicad_pcb, nfc_copy_cat.sch]
2019-12-16 nfc board v3
    [nfc_copy_cat.kicad_pcb, nfc_copy_cat.sch]
2020-01-02 add labels pinout
    [nfc_copy_cat.kicad_pcb]
2020-01-02 best labels description
    [nfc_copy_cat.kicad_pcb]
2020-01-09 remove c3
    [nfc_copy_cat.kicad_pcb]
2020-01-28 spi flash
    [nfc_copy_cat.sch]
2020-01-29 fix usb and leds
    [nfc_copy_cat.kicad_pcb]
2020-01-30 routeo charger
    [nfc_copy_cat.kicad_pcb]
2020-02-04 fix push and routeo samd
    [nfc_copy_cat.kicad_pcb]
2020-02-06 change leds and res
    [nfc_copy_cat.kicad_pcb]
2020-02-06 change led 1, res and push
    [nfc_copy_cat.kicad_pcb]
2020-02-07 routeo 3v and samd
    [nfc_copy_cat.kicad_pcb]
2020-02-07 routeo reset and usb
    [nfc_copy_cat.kicad_pcb]
2020-02-07 routeo gnd
    [nfc_copy_cat.kicad_pcb]
2020-02-08 change screws
    [nfc_copy_cat.kicad_pcb]
2020-02-08 chance c4 eschema
    [nfc_copy_cat.sch]
2020-02-08 fix c5, c2 y c1 and sw2
    [nfc_copy_cat.kicad_pcb]
2020-02-08 gnd plane
    [nfc_copy_cat.kicad_pcb]
2020-02-11 change routeo
    [nfc_copy_cat.kicad_pcb]
2020-02-11 fix c5 and sc
    [nfc_copy_cat.kicad_pcb]
2020-02-11 fix logos
    [nfc_copy_cat.kicad_pcb]
2020-02-11 logos ok, and labels
    [nfc_copy_cat.kicad_pcb]
2020-02-12 fix pin
    [nfc_copy_cat.kicad_pcb]
2020-02-13 chance labels
    [nfc_copy_cat.kicad_pcb]
2020-02-20 update silkS
    [nfc_copy_cat.kicad_pcb]
2020-04-15 fix caps and routes
    [nfc_copy_cat.kicad_pcb]
2021-04-16 fix caps, change SPI flash and LEDs, add ON/OFF
    [nfc_copy_cat.sch]
2021-04-16 update pins SPI Flash OK
    [nfc_copy_cat.sch]
2021-04-16 add SPI flash test
2021-04-21 change battery source driver
    [nfc_copy_cat.sch]
2022-01-11 update kicad 6
    [nfc_copy_cat.kicad_pcb, nfc_copy_cat.kicad_sch]
2022-03-18 Add labels and change ON
    [nfc_copy_cat.kicad_pcb, nfc_copy_cat.kicad_sch]
